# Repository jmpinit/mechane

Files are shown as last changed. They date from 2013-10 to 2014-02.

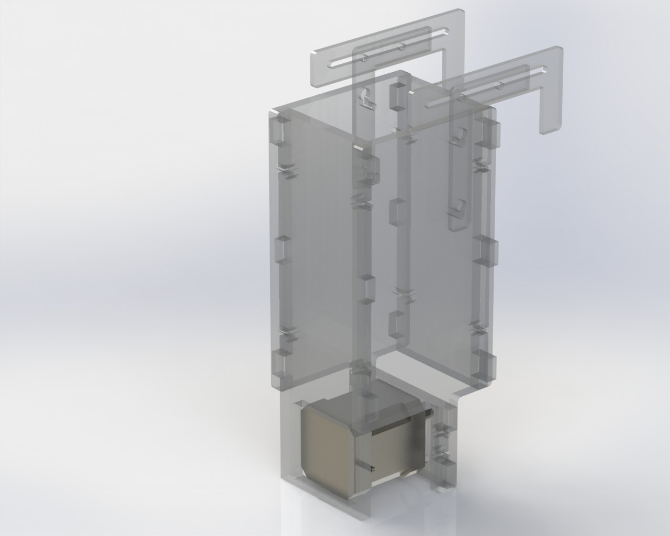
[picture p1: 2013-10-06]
hard/eyecandy/2doodle/2doodle-acrylic.jpg

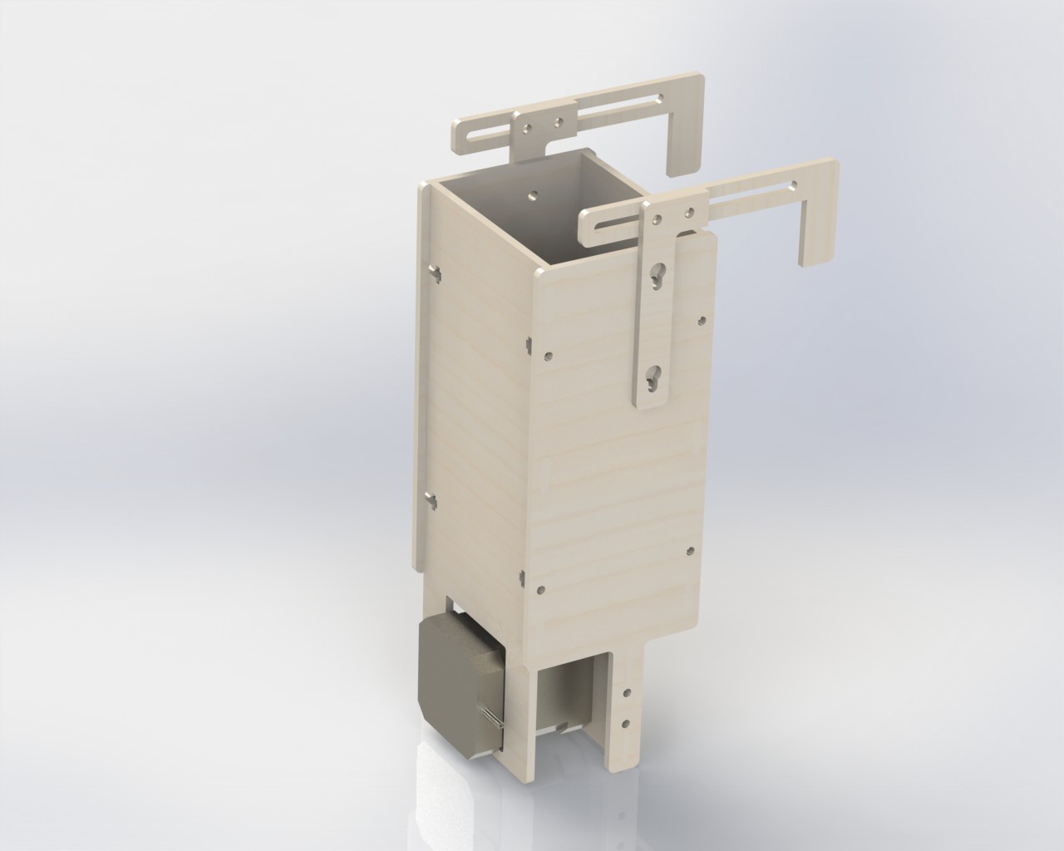
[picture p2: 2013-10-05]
hard/eyecandy/2doodle/2doodle-metal.jpg

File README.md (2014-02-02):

Mechane
=======

render of mechane's case

Purpose
-------

### In the Name

> A mechane or machine was a crane used in Greek theatre… Made of wooden beams and pulley systems, the device was used to lift an actor into the air, usually representing flight. This stage machine was particularly used to bring gods onto the stage from above, hence the Latin term deus ex machina (“god out of the machine”).

### Modular, Computerized Winch or Motor System

Mechane consists of fist-sized, wireless winch/motor modules and a Bluetooth/USB interface block. The modules are designed to work individually or collaboratively in groups, moving objects through space under the command of a nearby phone, tablet, laptop, or PC, or remotely over the Internet. One module gives 1 dimension of movement, to pull window blinds or pan a camera, for example. Two modules give two dimensions of movement, to create a drawbot or pan and tilt a camera. Three or more modules give full three dimensional movement, to carry small objects to arbitrary x, y, and z coordinates like in [this project](http://www.youtube.com/watch?v=g6v9cSiqf6A) from Penn State University.

Origin
------

Mechane started as a project to create a modular, wireless, easy-to-use drawbot system called [2doodle](http://2doodle.us/) for the [HackMIT hackathon](http://www.hackmit.org/).

Team
----

* [Skyler Adams](http://cirrus.scripts.mit.edu/blog/) - ME
* [Corey Walsh](http://coreyhwalsh.com/) - CS/Web
* [Owen](http://owen-t.me/) [Trueblood](http://hackniac.com/) - EE/CE

The three of us are students at MIT.

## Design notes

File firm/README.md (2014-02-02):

Firmware
========

* __radio__ - wireless firmware
* __serial__ - debug firmware using direct wired serial connection
* __*_test__ - firmware to test specific hardware submodule

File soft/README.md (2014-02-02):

Software
========

* __python__ - python API to control motor module
* __web__ - graphical motor module web interface

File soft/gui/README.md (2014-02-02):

Mechane GUI
===========

Goal
----

GUI usable by relatively non-technical person that allows useful control of all aspects of multiple Mechane motor modules.

Language
--------

Python, making use of the Mechane Python API.

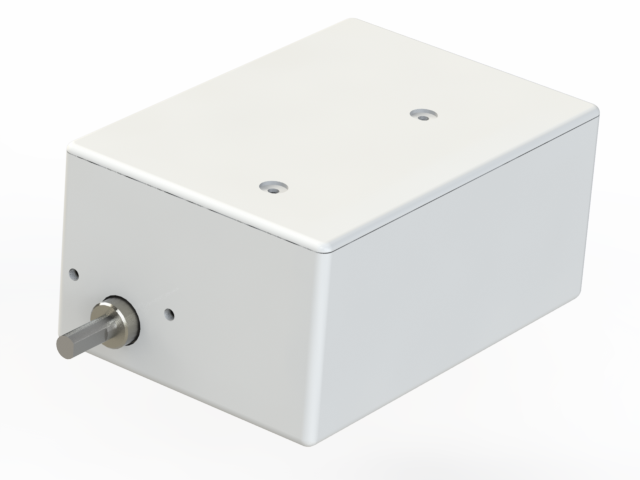
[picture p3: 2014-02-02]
hard/eyecandy/proto/proto-outer.png

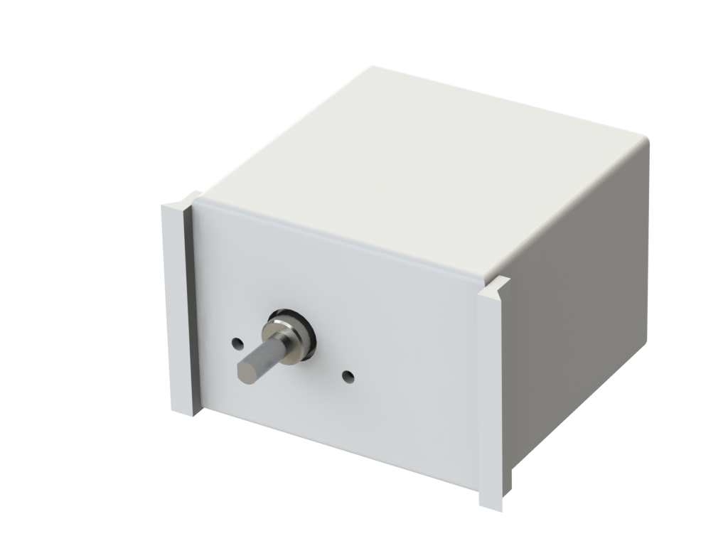
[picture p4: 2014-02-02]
hard/eyecandy/final/final-outer.png

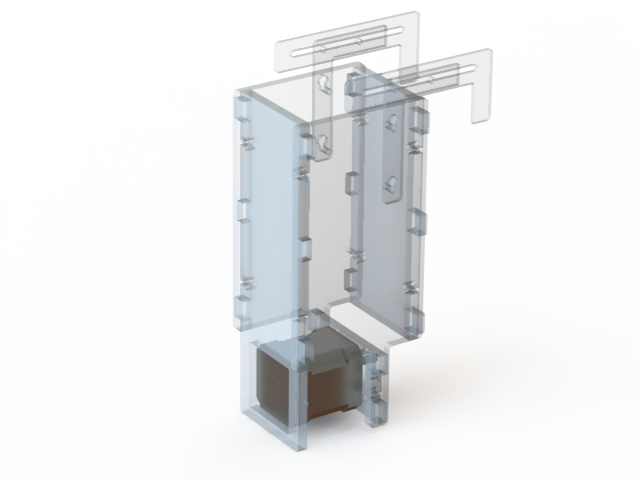
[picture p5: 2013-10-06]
hard/eyecandy/2doodle/2doodle-acrylic-transparent.png

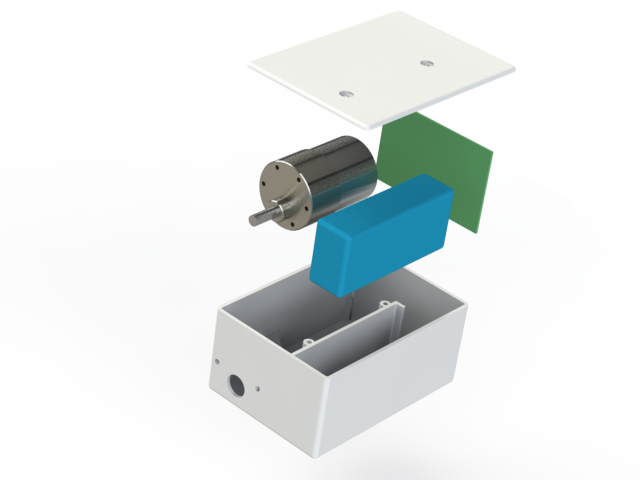
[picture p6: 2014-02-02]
hard/eyecandy/proto/proto-exploded.png

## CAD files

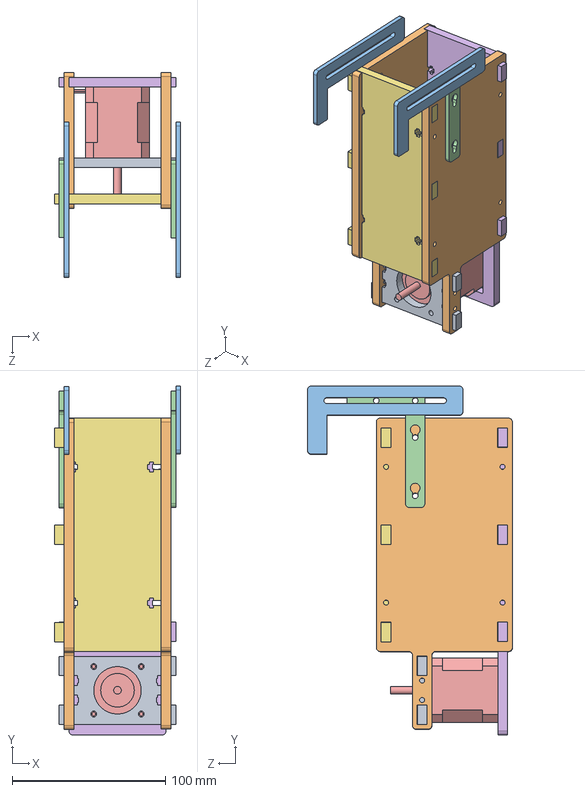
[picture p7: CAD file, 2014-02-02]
hard/CAD/assem.SLDASM
82.6 x 228.0 x 134.0 mm
stepper_faceplate
side x 2
clamp2 x 2
clamp1 x 2
nema17
front
back

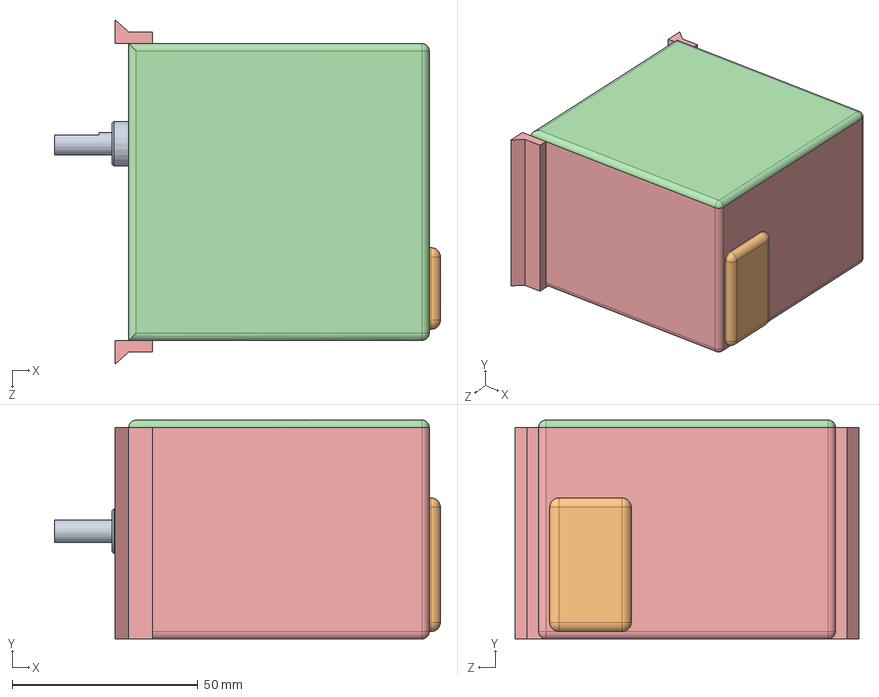
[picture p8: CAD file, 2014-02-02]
hard/CADv2/assem.SLDASM
104.0 x 59.0 x 92.7 mm
gear_motor
lipo
pcb
topcase
bottomcase

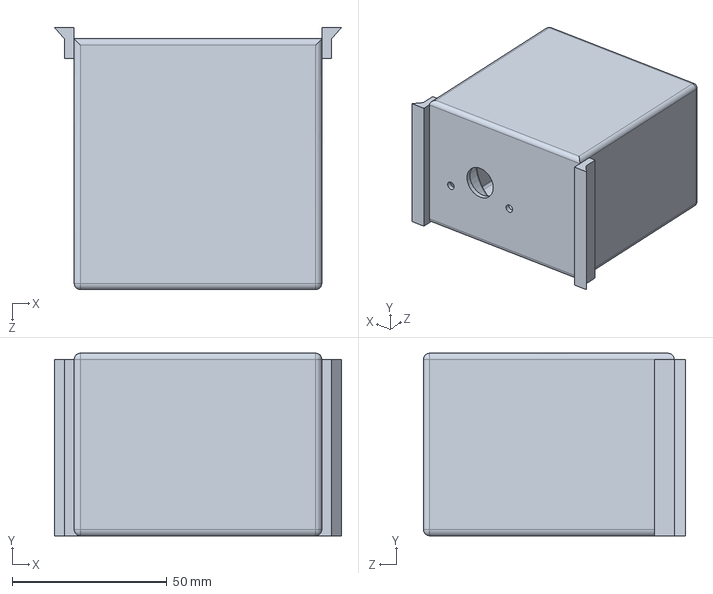
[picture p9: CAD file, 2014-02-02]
hard/CADv2/case_full.SLDPRT
92.7 x 59.0 x 84.6 mm

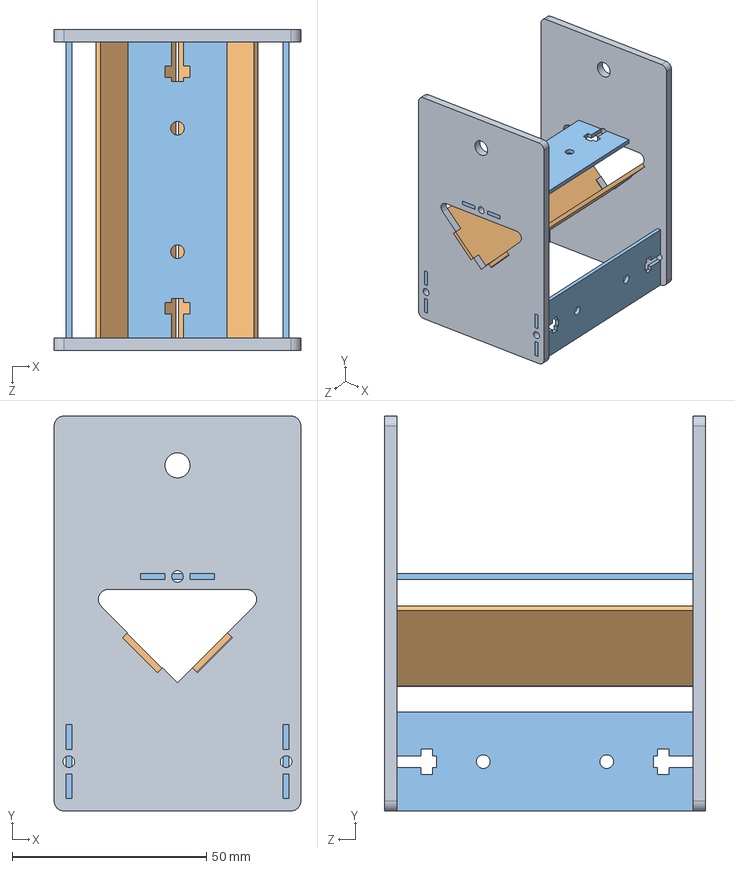
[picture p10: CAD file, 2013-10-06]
hard/CAD/pen_holder.SLDASM
63.5 x 101.6 x 82.6 mm
carriage x 2
kinematic_coupler x 2
kinematic_screwmount x 3

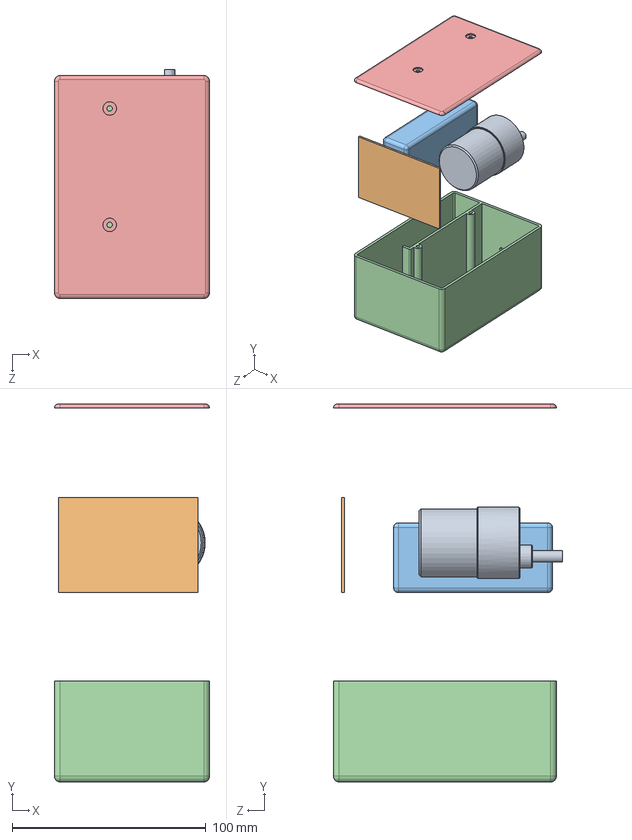
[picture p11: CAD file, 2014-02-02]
hard/CADv2/case_test.SLDASM
80.0 x 194.9 x 118.2 mm
gear_motor
pcb
lipo
bottomcase
topcase

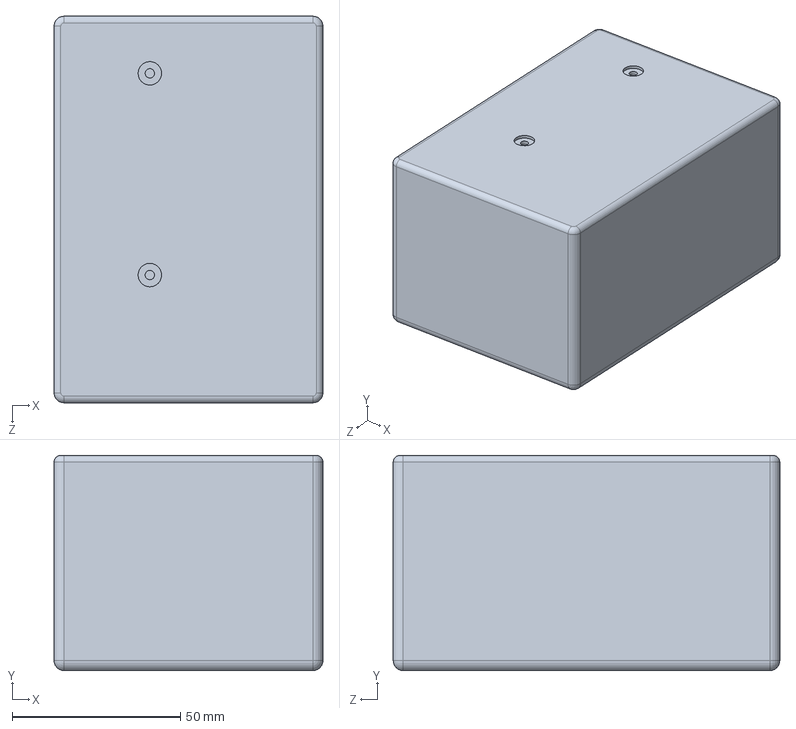
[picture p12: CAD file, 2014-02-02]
hard/CADv2/case_bottom.SLDPRT
80.0 x 64.0 x 115.0 mm

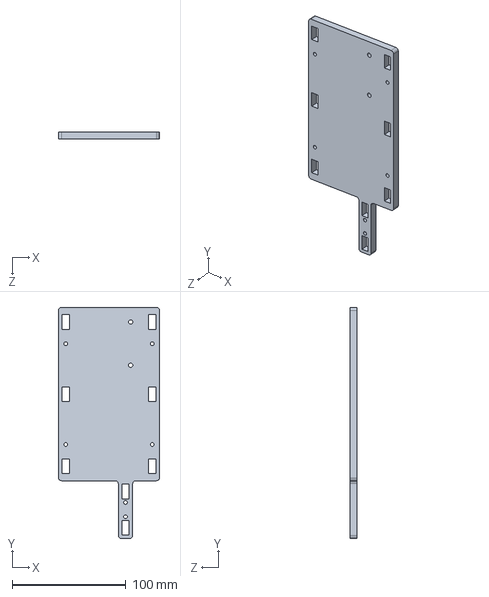
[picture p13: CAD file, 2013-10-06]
hard/CAD/side.SLDPRT
88.9 x 203.2 x 6.35 mm

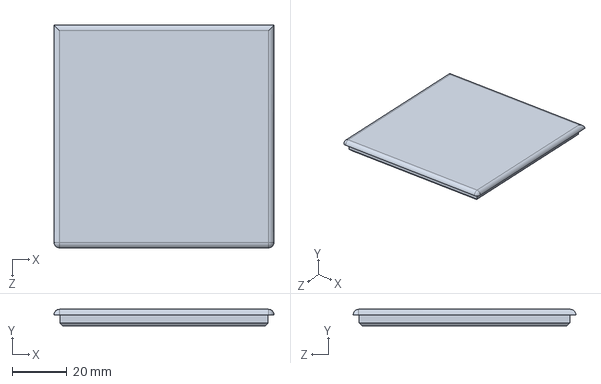
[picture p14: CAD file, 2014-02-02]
hard/CADv2/topcase.sldprt
80.0 x 6.00 x 81.0 mm

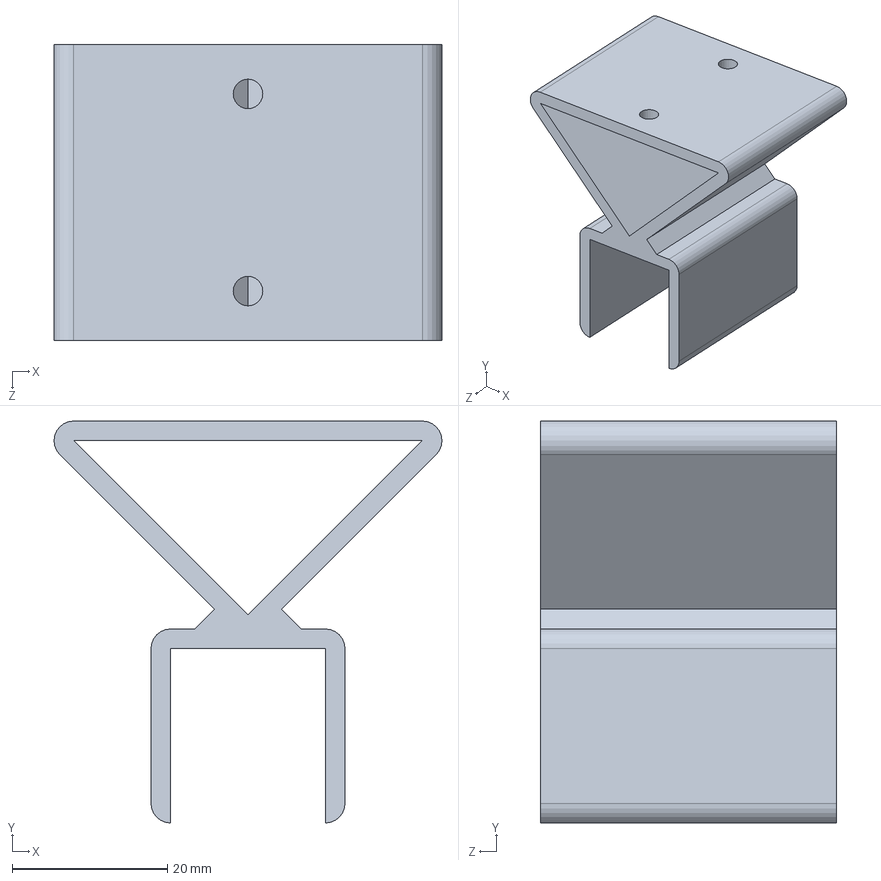
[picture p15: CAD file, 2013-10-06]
hard/CAD/3dprint_head.SLDPRT
50.0 x 51.8 x 38.1 mm

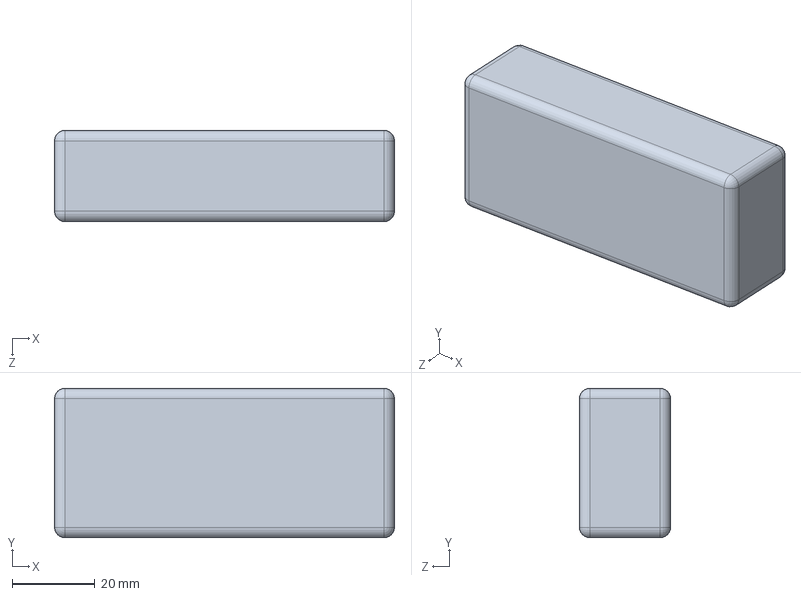
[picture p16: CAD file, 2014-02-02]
hard/CADv2/lipo.SLDPRT
82.0 x 36.0 x 22.0 mm

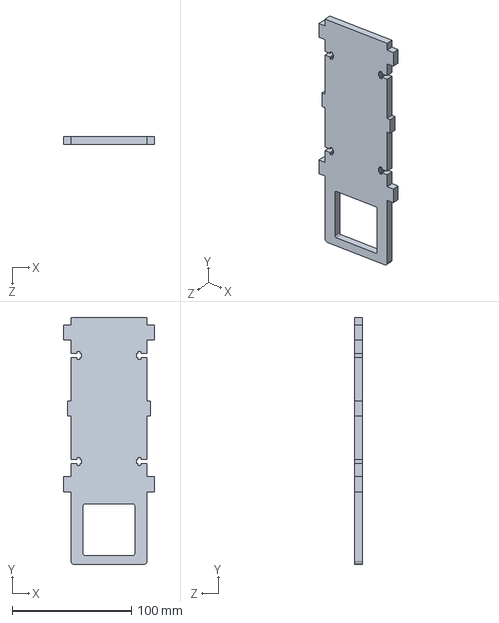
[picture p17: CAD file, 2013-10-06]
hard/CAD/front.SLDPRT
76.2 x 207.0 x 6.35 mm

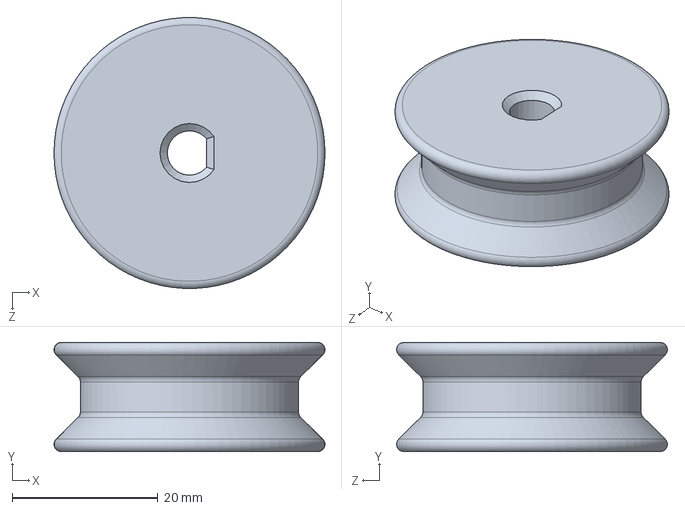
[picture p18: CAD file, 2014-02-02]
hard/CADv2/pulley.SLDPRT
37.2 x 15.0 x 37.2 mm

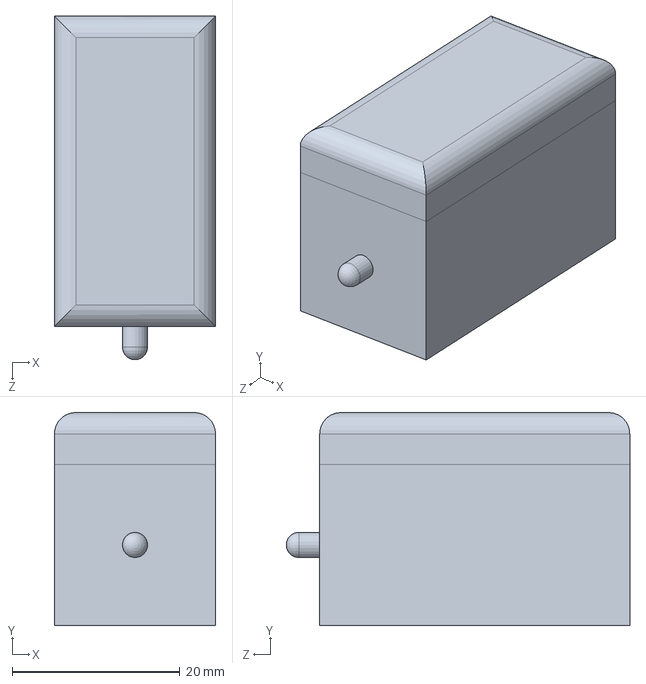
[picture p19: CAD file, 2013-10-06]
hard/CAD/solenoid_dummy.SLDPRT
19.2 x 25.4 x 41.0 mm

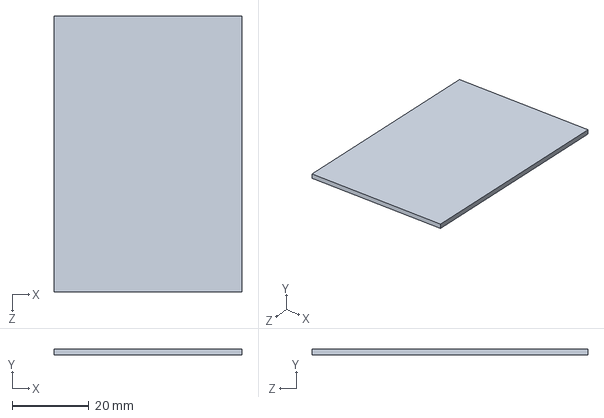
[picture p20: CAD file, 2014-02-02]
hard/CADv2/pcb.SLDPRT
49.0 x 1.50 x 72.0 mm

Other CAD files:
hard/CAD/back.SLDPRT
hard/CAD/clamp2.SLDPRT
hard/CAD/stepper_faceplate.SLDPRT
hard/CADv2/gear_motor.SLDPRT
hard/CAD/carriage.SLDPRT
hard/CAD/clamp1.SLDPRT
hard/CAD/kinematic_coupler.SLDPRT
hard/CAD/kinematic_screwmount.SLDPRT
hard/CAD/nema17.SLDPRT
hard/CAD/pcb_volumedummy.SLDPRT
hard/CAD/printhead.SLDPRT
hard/CAD/spool.SLDPRT
hard/CADv2/bottomcase.sldprt
hard/CADv2/topcase.STL

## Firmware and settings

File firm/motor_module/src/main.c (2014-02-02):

#include <stdio.h>
#include <stdint.h>
#include <stdbool.h>

#include <avr/io.h>
#include <avr/interrupt.h>
#include <util/delay.h>

#include "Led.h"
#include "Serial.h"
#include "Motor.h"
#include "rfm12.h"

#define forever for(;;)
// constants

#define NUM_SIZE 5 // len of number params in digits

Motor motor;

uint16_t decode(char* buffer, char* top) {
	uint16_t value = 0;
	static const uint16_t lookup[] = { 1, 10, 100, 1000, 10000 };

	uint8_t place = 0;
	while(top > buffer) {
		char c = *(--top);
		
		if(c >= '0' && c <= '9') {
			uint8_t digit = c - '0';
			value += digit*lookup[place++];
		}
	}

	return value;
}

typedef enum {
	LISTEN,
	READ,
	CMD,
	CONFUSED
} Mode;

char buffer[16];

int main(void) {
	// led init
	DDRC |= (1 << LED_GREEN) | (1 << LED_RED);
	PORTC |= 1 << LED_RED;

	uart_init(27); // 19200 baud
	motor_init();
	rfm12_init();

	uart_tx_str("hello world!\r\n");

	sei();

	// control

	char digit_buffer[NUM_SIZE];
	char* digit = digit_buffer;

	Mode mode = LISTEN;

	forever {
		/*sprintf(buffer, "vel=%d\r\n", (int)motor.vel);
		uart_tx_str(buffer);*/
		/*for(int i=0; i<motor.pos; i++)
			uart_tx('*');
		uart_tx_str("\r\n");*/
		/*int v = motor.vel + 32;
		int tv = motor.target_vel + 32;
		if(v < 0) v = - v;
		if(tv < 0) tv = -tv;
		for(int i=0; i<v || i<tv && i<64; i++) {
			if(i < tv && i < v) {
				uart_tx('*');
			} else if(i < v) {
				uart_tx('+');
			} else if(i < tv) {
				uart_tx('x');
			}
		}
		uart_tx_str("\r\n");*/
		
		/*uart_tx(27);
		uart_tx('[');
		uart_tx('2');
		uart_tx('J');

		uart_tx(27);
		uart_tx('[');
		uart_tx('H');

		sprintf(buffer, "pos=%u\r\n", motor.pos);
		uart_tx_str(buffer);
		sprintf(buffer, "vel=%d\r\n", motor.vel);
		uart_tx_str(buffer);
		sprintf(buffer, "target pos=%u\r\n", motor.target_pos);
		uart_tx_str(buffer);
		sprintf(buffer, "target vel=%d\r\n", motor.target_vel);
		uart_tx_str(buffer);
		*/

		while(uart_available()) {
			char c = uart_read_buff();
			uart_tx(c);

			if(mode == CONFUSED) {
				// line end brings clarity
				if(c == '\n' || c == '\r') mode = LISTEN;
			} else {
				if(mode == CMD) {
					switch(c) {
						case 'p': // set position mode
						case 'P':
							motor.mode = POSITION;
							break;
						case 'v': // set velocity mode
						case 'V':
							motor.mode = VELOCITY;
							break;
						case 's': // status
						case 'S':
							uart_tx_str("I am okay.\n\r");
							uart_tx_str("motor.mode: ");
							switch(motor.mode) {
								case POSITION:		uart_tx_str("position\n\r"); break;
								case VELOCITY:		uart_tx_str("velocity\n\r"); break;
							}
							break;
						case 'k': // kill (de-energize)
						case 'K':
							motor_stop();
							break;
						case 'b':
						case 'B': // brake
							motor_brake();
							break;
						case 'i':
						case 'I':
							sprintf(buffer, "pos=%u\r\n", motor.pos);
							uart_tx_str(buffer);
							sprintf(buffer, "vel=%d\r\n", motor.vel);
							uart_tx_str(buffer);
							sprintf(buffer, "target pos=%u\r\n", motor.target_pos);
							uart_tx_str(buffer);
							sprintf(buffer, "target vel=%d\r\n", motor.target_vel);
							uart_tx_str(buffer);
							break;
					}

					mode = LISTEN;
				} else {
					if((c >= '0' && c <= '9') || c == '+' || c == '-' || c == 'p' || c == 'd' || c == 'i') {
						// starting a number?
						if(mode == LISTEN) {
							mode = READ;
							digit = digit_buffer;
						}

						// save the digit
						if(digit >= digit_buffer + NUM_SIZE) {
							mode = CONFUSED; // too many digits
						} else {
							*(digit++) = c;
						}
					} else {
						if(c == '\n' || c == '\r') {
							if(mode == READ) { // use the parameter that was read in
								uint16_t num = decode(digit_buffer, digit);

								switch(digit_buffer[0]) {
									case '+':
										switch(motor.mode) {
											case POSITION:
												motor_set_pos(num);
												break;
											case VELOCITY:
												motor_set_vel(num);
												break;
										}
										break;
									case '-':
										switch(motor.mode) {
											case POSITION:
												motor_set_pos(-num);
												break;
											case VELOCITY:
												motor_set_vel(-num);
												break;
										}
										break;
									// PID set
									case 'p':
										//motor.pid.Kp = ((float)num)/1000.0;
										break;
									case 'd':
										//motor.pid.Kd = ((float)num)/1000.0;
										break;
									case 'i':
										//motor.pid.Ki = ((float)num)/1000.0;
										break;
								}
							}

							mode = LISTEN;
						} else if(c == '\\') {
							if(mode != LISTEN) {
								mode = CONFUSED;
							} else {
								mode = CMD;
							}
						} else {
							mode = CONFUSED;
						}
					}
				}
			}
		}
	}

	return 0;
}

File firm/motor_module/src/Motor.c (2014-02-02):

#include <stdint.h>
#include <util/delay.h>
#include <avr/io.h>
#include <avr/interrupt.h>
#include <math.h>

#include "Motor.h"
#include "Led.h"

#define CLK_NONE	1
#define CLK_8		2
#define CLK_64		3
#define CLK_256		4
#define CLK_1024	5

#define PIN_OFF(port,pin) (port) |= 1 << (pin);
#define PIN_ON(port,pin) (port) &= ~(1 << (pin));

#define MOTOR_DISABLE() PIN_OFF(PORTD, PIN_M_EN);
#define MOTOR_ENABLE() PIN_ON(PORTD, PIN_M_EN);

uint16_t dt_i = 0;
uint32_t pos_i = 0;

// quadrature encoder interrupt
volatile uint8_t hist_portb = 0xFF;

volatile long overflows = 0;
ISR(TIMER1_COMPA_vect) {
	PINC |= 1 << LED_GREEN;

	/*switch(motor.mode) {
		case POSITION:
			motor.target_vel = pid_calc(&motor.pid, motor.pos, motor.target_pos);
			break;
		case VELOCITY:
			break;
	}*/

	float correction = 0; //pid_calc(&motor.pid, motor.vel, motor.target_vel);
	if(motor.vel > motor.target_vel) {
		correction = -1;
	} else {
		correction = 1;
	}

	if(motor.target_vel < 0) {
		TCCR0A &= ~(1 << COM0B0);
		TCCR0A &= ~(1 << COM0B1);
		TCCR0A |= (1 << COM0A0);
		TCCR0A |= (1 << COM0A1);

		//OCR0A = 128;

		/*if() {
			
		} else {

		}*/
		float new = OCR0A - correction;
		if(new > 255) new = 255;
		if(new < 0) new = 0;
		OCR0A = new;
	} else {
		TCCR0A &= ~(1 << COM0A0);
		TCCR0A &= ~(1 << COM0A1);
		TCCR0A |= (1 << COM0B0);
		TCCR0A |= (1 << COM0B1);

		OCR0B = 128;
		/*if() {

		} else {

		}*/
		float new = OCR0B - correction;
		if(new > 255) new = 255;
		if(new < 0) new = 0;
		OCR0B = new;
	}
	
	// calc velocity
	motor.vel = motor.pos - pos_i;
	pos_i = motor.pos;

	//overflows++;
}

ISR(PCINT0_vect) {
	uint8_t changed;

	changed = PINB ^ hist_portb;
	hist_portb = PINB;

	if(changed & (1 << PB0)) { // pb0 changed
		// dx 
		if(PINB & (1 << PB0)) { // pb0 rising edge
			if(PINB & (1 << PB1)) { // pb1 high or low?
				motor.pos--;
			} else {
				motor.pos++;
			}
		}
		
		/*
		// dt 
		uint16_t dt_f = (TCNT1 & 0x7FFF);
		double dt = dt_f - dt_i;
		if(dt < 0) {
			// we did not go back in time
			dt += overflows * 0x7FFF;
			overflows = 0;
		}
		dt_i = dt_f;

		// velocity
		if(dt != 0) motor.vel = 0x7FFF * (motor.pos - pos_i) / dt;
		pos_i = motor.pos;
		*/
	}
}

float pid_calc(PidData* prefs, float current, float target) {
	float error = target - current;

	if(fabs(error) > prefs->epsilon)
		prefs->integral = prefs->integral + error*prefs->dt;
	float derivative = (error - prefs->pre_error)/prefs->dt;
	float output = prefs->Kp*error + prefs->Ki*prefs->integral + prefs->Kd*derivative;

	// update error
	prefs->pre_error = error;

	return output;
}

void pid_reset() {
	motor.pid.integral	= 0.0;
	motor.pid.pre_error	= 0.0;
}

void motor_init() {
	motor.mode			= VELOCITY;
	motor.target_vel	= 0;

	motor.pid.Kp		= 3.0;
	motor.pid.Kd		= 0.1;
	motor.pid.Ki		= 0.014;

	/*motor.pid.Kp		= 1.0;
	motor.pid.Kd		= 1.0;
	motor.pid.Ki		= 0.0;*/

	// pin change interrupt
	// for quadrature encoder
	/*PCICR = 1 << PCIE0;
	PCMSK0 = 1 << PCINT0;*/

	// motor control pins
	DDRD |= 1 << PIN_M_EN;
	DDRD |= (1 << PIN_M_1A) | (1 << PIN_M_2A);
	MOTOR_DISABLE();

	// setup 16 bit timer
	TCCR1B |= CLK_8;
	TIMSK1 |= 1 << OCIE1A; // interrupt on OCR1A compare match
	OCR1A = 0xFFF;

	// pwm using timer0
	// phase correct, OCR0A top, no prescale
	TCCR0A = (1 << COM0A0) | (1 << COM0A1) | (1 << WGM00);
	TCCR0B = (1 << CS00);

	OCR0A = 255; // off
	OCR0B = 255; // off
}

void motor_set_pos(uint32_t pos) {
	motor.mode = POSITION;
	motor.target_pos = pos;
}

void motor_set_vel(int32_t vel) {
	motor.mode = VELOCITY;
	motor.target_vel = vel;
	MOTOR_ENABLE();
}

void motor_stop() {
	pid_reset();
	PIN_OFF(PORTD, PIN_M_1A);
	PIN_OFF(PORTD, PIN_M_2A);
}

void motor_brake() {
	MOTOR_DISABLE();

	pid_reset();
	PIN_OFF(PORTD, PIN_M_1A);
	PIN_OFF(PORTD, PIN_M_2A);
}

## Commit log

2013-10-05 basic cad stuffs
    [assem.SLDASM, back.SLDPRT, clamp1.SLDPRT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]
2013-10-05 size changes.
    [assem.SLDASM, back.SLDPRT, front.SLDPRT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]
2013-10-05 Folder organization.
    [assem.SLDASM, back.SLDPRT, clamp1.SLDPRT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]
2013-10-05 Completed pen holder.
    [carriage.SLDPRT, kinematic_coupler.SLDPRT, kinematic_screwmount.SLDPRT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]
2013-10-06 changed materials to account for plexiglas, added 3d printed carriage.
    [3dprint_head.SLDPRT, assem.SLDASM, back.SLDPRT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]
2013-10-06 Added final changes to frame and new eye candy.
    [side.SLDPRT]
2013-10-06 pushing arduino stepper control
2013-12-07 V1 Circuit and schematic (routed).
    [mechane.fzz]
2013-12-08 Added encoder.
    [mechane.fzz]
2013-12-08 Decode quadrature encoder output and show direction on two LEDs.
2013-12-08 c99 to gnu99 for inline assembly code.
2013-12-08 Calculate speed using timer and encoder. Report speed over serial.
2013-12-08 Moved control of motor to PWM capable pins.
    [mechane.fzz]
2013-12-08 Pin swap so 'higher' pin goes to 'higher' pin.
    [mechane.fzz]
2013-12-08 Motor velocity control in both directions using PWM.
2013-12-08 Added pull-down resistors on H Bridge inputs to prevent motor running when CPU is off / undefined.
    [mechane.fzz]
2013-12-08 Motor target speed initialized in motor initializer. Report mode with status.
2014-01-17 Working radio test. Interrupts and frequency configured correctly.
    [main.c]
2014-01-17 perfboard design v1
    [mechane.fzz, mechane_perf_v1.fzz]
2014-01-18 Flash with arduino bootloader.
2014-01-18 Accurate measurement of position and speed. Track a given target velocity.
2014-01-18 Basic case done
    [assem.SLDASM, bottomcase.sldprt, case_bottom.SLDPRT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]
2014-01-26 Case v3?
    [bottomcase.sldprt, case_full.SLDPRT, topcase.sldprt]
2014-01-26 renders yeah!
    [assem.SLDASM, bottomcase.sldprt, case_full.SLDPRT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]
2014-01-29 Tweaked UART initialization as temporary fix for strange change in hardware clock rate.
    [main.c]
2014-01-30 Made pulley
    [bottomcase.sldprt, pulley.SLDPRT]
2014-02-02 added derpy mechane python module
    [topcase.sldprt]
2014-02-03 random python stuff +3d printed brackets
